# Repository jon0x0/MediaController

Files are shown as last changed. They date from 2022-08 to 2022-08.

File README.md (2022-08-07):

# MediaController

Design and programming by Jon Becker

This is a media controller to support sound art installations.

Goals are:
###  An external 'outside' button to open the door.
###  An internal 'user' button to indicate the user is in place and ready to begin, and to abort the experience if the user is uncomfortable continuing.
###  An operator button to assist with aborting the media.
###  LEDs on the buttons to indicate functions and status.
###  Bright internal RGBW LEDs (here implemented by Adafruit 4W Dotstars) which can be changed to a different color and brightness and controlled as desired.
###  A linear actuator to open and close the door.
###  A relay to control the media (on to reset and play, off to stop playing).

The system is implemented with an Adafruit Feather M4 Express microcontroller, and programmed in C using the Arduino IDE.
It was developed on Arduino IDE 1.8.19.
The software uses a realtime state machine architecture (where each state finishes very quickly), with a low-level (fast) state machine which controls button LED glow and flash behavior (and only a single 12ms delay for LED persistence), and a high level state machine for button transitions, device actuation etc.

# Libraries:
To install, the following libraries are needed (they can be installed through the Arduino Library Manager).
## 'Sparkfun QWIIC Relay' library
## 'Adafruit BUSIO' library
## 'Adafruit seesaw' library (for the button controller)

# Hardware used:

## [Adafruit Feather M4 Express](https://www.adafruit.com/product/3857)

## [Featherwing Breakout](https://www.adafruit.com/product/2926)

## [Short headers](https://www.adafruit.com/product/3002) and [stacking headers](https://www.adafruit.com/product/2830)

## [Adafruit 4W RGBW pixels](https://www.adafruit.com/product/5408)

Note that Adafruit recommends a 1000 uF capacitor (watch polarity) across the +5V and GND pins of the dotstars, and a 300-500 ohm resistor in series with the data line. Without this it *will* misbehave.

## Level shifter
This [level shifter](https://learn.sparkfun.com/tutorials/txb0104-level-shifter-hookup-guide) is used to shift interface levels from 3.3V of the M4 Express board to the 5V level required by the Dotstar LEDs.

## Sparkfun QWIIC / I2C relay module
[COM-15093 relay module](https://www.sparkfun.com/products/15093)

Works with Sparkfun QWIIC Relay library  (arduino auto library manager)
https://learn.sparkfun.com/tutorials/qwiic-single-relay-hookup-guide

## Buttons:
[Mini Arcade Buttons with integrated LED](https://www.adafruit.com/product/3432)

the bottom of the button has arrows for + and - on the LED connections.

## [Spade to JST-XH connectors](https://www.adafruit.com/product/1152)

## [QWIIC/STEMMA Button interface](https://www.adafruit.com/product/5296)

This is a button interface as a well as an LED controller for buttons with integrated LEDs.
driver in library manager is 'adafruit seesaw'
example in 'LEDArcade_1x4'
dependence is 'Adafruit BUSIO'

## [QWIIC breakout board](https://www.sparkfun.com/products/16790)

## Linear Actuator
[Yuelianart 8" Stroke Tracker Actuator Multi Function Linear Electric Actuator 12v Linear Actuator Stroke Speed 10mm/s 900N Load Capacity](https://www.amazon.com/gp/product/B09PYLGBRK/)
The spec says 2A no load, up to 7A with load. 12V@5A should be sufficient for most uses, but 7A might be needed for the highest loads. 

Note that this actuator has built in limit switches that will stop it at each end of the actuation.

## Motor driver:
[HiLetgo BTS7960](https://www.amazon.com/HiLetgo-BTS7960-Driver-Arduino-Current/dp/B00WSN98DC/)

Some diagrams and code 
https://www.youtube.com/watch?v=QvXa6GKLu6E

motor controller example
https://create.arduino.cc/projecthub/Fouad_Roboticist/dc-motors-control-using-arduino-pwm-with-l298n-h-bridge-d6ec91

Another example and library
https://robojax.com/learn/arduino/?vid=robojax_BTS7960_motor_driver#google_vignette

## Misc JST-SM wire to wire [connectors](https://www.adafruit.com/product/1663) (2,3,4,6 pins)

# Wiring pinout
See [here](https://docs.google.com/spreadsheets/d/1ZAK95VV2u1BcN2Gdv8SZK7Fb-S8OxHLf3jOhQMFysT0/edit?usp=sharing)

# Cables needed:
 These cables may be overkill, but the choice was influenced by how long they needed to be (which makes low resistance desirable), current capacity required (in some cases) and what cable was readily available.
 Cable was purchased from [this](https://www.amazon.com/gp/product/B07Y34F1ZV/) cable family.
 
 | Cable  | Length  | Spec  |
|---|---|---|
| outside+operator button  |  6m | 6c 20ga  |
| motor  | 6m  | 6c 18ga, tripled  |
| inside button  | 3m  | 4c 18ga  |
| lights  | 6m  | 3c 18ga  |
| audio footswitch | 3m | 3c 18ga |

# Operational notes:

When I tried to make an extension cable for the 4W Dotstar chain I couldn't get it working. I tried to build a shorter one which also didn't work. Then I remembered that the Dotstars kind of boost the signal at each stage, so I tried inserting the extension after the first Dotstar, and that worked (with either the 6m or 3m version).  I included both extensions I made. At the moment there are 5 total Dotstars to work with so you could even completely cover up the first one if you want and you still have a decent number to work with.

Probably I could have tried to change the resistor which is in line with the Dotstar data line to increase the drive strength- currently 330 ohm per Adafruit's recommendation of 300-500 ohms (reducing this might have helped). Anyway it takes time to figure those kinds of things out.

The main thing you're going to have to be careful with is to not reverse the 5V and 12V power, that would be disastrous. They are pretty well marked but it would definitely be possible to switch them.

The other thing is that you will still need a MicroUSB cable and a USB wall supply to power the processor (Adafruit Feather M4 Express).
And you will need a 1/4" plug cable to wire into the relay connection to start/stop the audio player.

I would recommend this powerup order: 5V, then USB power to the processor, then 12V. And the reverse to power down (or all at once with a power strip).

The enclosure was designed (with Fusion 360) so you can mount it to a surface and then screw the cover on top of it (it uses [M3 heat-set threaded inserts](https://www.mcmaster.com/94180A331/)). Also you can route cables either out of a slot on one edge of the cover or you can route cables through a slot in the base (it may not be possible but it's there if useful).

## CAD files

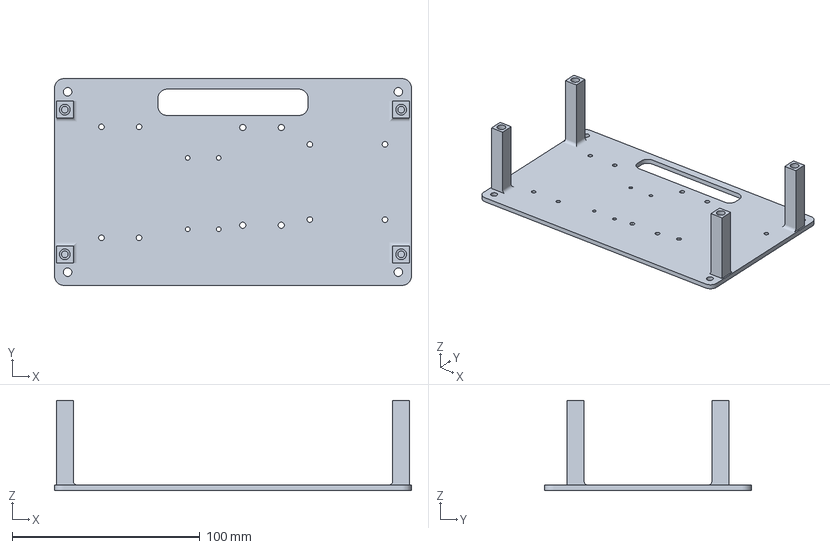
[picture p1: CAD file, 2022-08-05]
MediaControllerMountingTray v2.3mf
190.0 x 110.0 x 48.0 mm

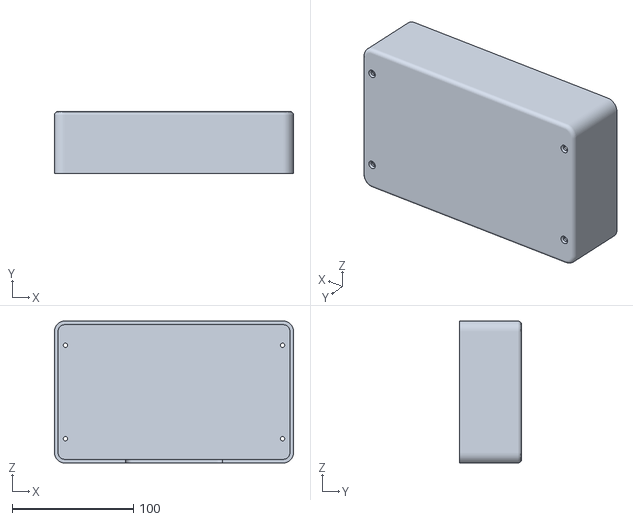
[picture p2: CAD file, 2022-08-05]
MediaControllerCover v3.stl
197.0 x 51.2 x 117.0

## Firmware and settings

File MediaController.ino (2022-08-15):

// Media Controller software
// Jon Becker 2022
// For Thembi Soddell's audio installation

// Master definitions

// Time from when user pushes button to when media starts (includes closing door).
#define BEGIN_CLOSING_DOOR_TO_MEDIA_START_SEC 20.0

// Total duration of media play before lights come on in floating point seconds. This should match the media play possibly plus a few seconds.
#define MEDIA_DURATION_SEC (12.0*60)

// Brightness of neopixel LEDs, 0-255 (255 is brightest).
#define NEOPIXEL_MASTER_BRIGHTNESS 255

// Number of Neopixels in the system.
#define NEOPIXEL1_COUNT 5

// Neopixel color. Each channel is 0 to 255.
#define NEOPIXEL_RED 255
#define NEOPIXEL_GREEN 0
#define NEOPIXEL_BLUE 0
#define NEOPIXEL_WHITE 50

// Speed of door motor (0-255). Probably want to leave this at 255. Even at full speed it's pretty slow. If it is too slow the actuator will not move.
#define MOTOR_SPEED 255

// Include Arduino Wire library for I2C

// Definitions for Arcade button+LED controller 1x4, from LEDArcade_1x4
#include "Adafruit_seesaw.h"
#include <seesaw_neopixel.h>

#define  DEFAULT_I2C_ADDR 0x3A

#define  SWITCH1  18  // PA01
#define  SWITCH2  19 // PA02
#define  SWITCH3  20 // PA03
#define  SWITCH4  2 // PA06
#define  PWM1  12  // PC00
#define  PWM2  13 // PC01
#define  PWM3  0 // PA04
#define  PWM4  1 // PA05


Adafruit_seesaw ss;

enum buttonledstates
{
  B_LEDON_STATE = 0,
  B_LEDON_STATE2,
  B_LEDOFF_STATE,
  B_LEDOFF_STATE2,
  B_LEDONLOW_STATE,
  B_LEDONLOW_STATE2,
  B_LEDGLOW_STATE,
  B_LEDGLOWPULSE_STATE,
  B_LEDGLOWPULSE_STATE2,
  B_LEDFLASH_STATE,
  B_LEDFLASH_STATE2,
  B_LEDFLASH_STATE3,
  B_LEDFADEIN_STATE,
  B_LEDFADEIN_STATE2
};

// Define the number of buttons in the system.
#define NBUTTONS 3

// Pushbutton LED glow pulse width modulation
uint8_t masterbuttonledpwm = 0;  // You could use this to synchronize multiple button glows.
// Button led pwm fro multiple buttons;
uint8_t buttonledpwm[NBUTTONS + 1];


// Definitions for the relay (used to control audio player)
#include <Wire.h>
#include "SparkFun_Qwiic_Relay.h"
#define RELAY_ADDR 0x18 // Alternate address 0x19
Qwiic_Relay relay(RELAY_ADDR);

// Definitions for the 4W GRBW Neopixels
#include <Adafruit_NeoPixel.h>
// Which pin on the Arduino is connected to the NeoPixels?
#define NEOPIXEL1_PIN    14

// Declare our NeoPixel strip object:
Adafruit_NeoPixel strip1(NEOPIXEL1_COUNT+1, NEOPIXEL1_PIN, NEO_RGBW + NEO_KHZ800);
// Argument 1 = Number of pixels in NeoPixel strip
// Argument 2 = Arduino pin number (most are valid)
// Argument 3 = Pixel type flags, add together as needed:
//   NEO_KHZ800  800 KHz bitstream (most NeoPixel products w/WS2812 LEDs)
//   NEO_KHZ400  400 KHz (classic 'v1' (not v2) FLORA pixels, WS2811 drivers)
//   NEO_GRB     Pixels are wired for GRB bitstream (most NeoPixel products)
//   NEO_RGB     Pixels are wired for RGB bitstream (v1 FLORA pixels, not v2)
//   NEO_RGBW    Pixels are wired for RGBW bitstream (NeoPixel RGBW products)


// Definitions for motor controller
#define MotorPin_D1_L  9 //Rpwm
#define MotorPin_D2_L  10 //Lpwm
#define MotorPin_E_L   11 //pwm enable (connected to two pins on the motor driver)


void setup()
{
  motor_setup();

  // put your setup code here, to run once:
  Serial.begin(115200);

//  while (!Serial) delay(10);   // wait until serial port is opened

  Serial.println(F("Media Controller"));

  // Initialize arcade button interface
  if (!ss.begin(DEFAULT_I2C_ADDR))
  {
    Serial.println(F("seesaw button controller not found!"));
    while (1) delay(10);
  }

  uint16_t pid;
  uint8_t year, mon, day;

  ss.getProdDatecode(&pid, &year, &mon, &day);
  Serial.print("seesaw button controller found PID: ");
  Serial.print(pid);
  Serial.print(" datecode: ");
  Serial.print(2000 + year); Serial.print("/");
  Serial.print(mon); Serial.print("/");
  Serial.println(day);

  if (pid != 5296)
  {
    Serial.println(F("Wrong seesaw button controller PID"));
    while (1) delay(10);
  }

  Serial.println(F("seesaw started OK!"));
  ss.pinMode(SWITCH1, INPUT_PULLUP);
  ss.pinMode(SWITCH2, INPUT_PULLUP);
  ss.pinMode(SWITCH3, INPUT_PULLUP);
  ss.pinMode(SWITCH4, INPUT_PULLUP);
  ss.analogWrite(PWM1, 127);
  ss.analogWrite(PWM2, 127);
  ss.analogWrite(PWM3, 127);
  ss.analogWrite(PWM4, 127);

  buttonledpwm[0] = 0; // unused but leave nothing uninitialized.
  for (int i = 1; i < NBUTTONS + 1; ++i)
    buttonledpwm[i] = 0;

  SetButtonLEDState(0, B_LEDON_STATE2);
  SetButtonLEDState(1, B_LEDGLOWPULSE_STATE);
  SetButtonLEDState(2, B_LEDGLOWPULSE_STATE);

  // Init the audio player relay
  Wire.begin();

  // Let's see
  if (!relay.begin())
    Serial.println("Check connections to Qwiic Relay.");
  else
    Serial.println("Relay control initialized.");

  Init_Neopixels();

} //setup()



void loop()
{
  // put your main code here, to run repeatedly:

  ProcStateMachine();

} // loop()

int state = 0;

enum states
{
  START_STATE = 0,
  ATTRACT_STATE,
  OPEN_DOOR_STATE,
  OPEN_DOOR_STATE2,
  WAIT_FOR_MEDIA_BUTTON_STATE,
  CLOSE_DOOR_STATE,
  PLAYING_MEDIA_STATE,
  PLAYING_MEDIA_STATE2
};

unsigned long statetimer;
unsigned long mediatimer;
unsigned long operatordebouncetimer;
unsigned long debouncetimer;

void ProcStateMachine()
{
  switch (state)
  {
    case START_STATE: // starting state. Use for some setup / going back to the beginning.
      // Nothing here at the moment
      TurnOffAudioPlayer();
      TurnNeopixelsOn();
      //SetButtonLEDState(0,B_LEDFADEIN_STATE);
      SetButtonLEDState(1, B_LEDGLOWPULSE_STATE);
      SetButtonLEDState(2, B_LEDOFF_STATE);
      operatordebouncetimer = SetTimer_sec(5.0);

      state++;
      Serial.println(F("Start state complete. Moving to attract state."));
      break;

    case ATTRACT_STATE:  // The initial state to glow button and wait for a button push.

      if (! ss.digitalRead(SWITCH1))
      {
        Serial.println("Switch 1 pressed");
        TurnNeopixelsOn();
        SetButtonLEDState(1, B_LEDFLASH_STATE);
        SetButtonLEDState(2, B_LEDGLOWPULSE_STATE);
        state++;
      }
      if (! ss.digitalRead(SWITCH3) && IsTimerFinished(operatordebouncetimer))    // Operator switch
      {
        Serial.println("Switch 3 pressed");
        Serial.println("Closing door.");
        CloseDoor();
        TurnNeopixelsOff();
        operatordebouncetimer = SetTimer_sec(5.0);
        // remain in this state.
      }
      break;

    case OPEN_DOOR_STATE:
      // actuate the door open
      OpenDoor();
      state++;
      break;

    case OPEN_DOOR_STATE2:
      state++;
      break;

    // waiting for the user to push the button inside to begin the media
    case WAIT_FOR_MEDIA_BUTTON_STATE:
      if (! ss.digitalRead(SWITCH3) )    // Operator switch
      {
        state = START_STATE; // reset back to the beginning.
      }

      if (! ss.digitalRead(SWITCH2))
      {
        Serial.println("Switch 2 pressed");
        CloseDoor();
        TurnNeopixelsOff();
        SetButtonLEDState(1, B_LEDFLASH_STATE);
        SetButtonLEDState(2, B_LEDONLOW_STATE); // turn on led steady and dim so it isn't a distraction in the dark. May want to dim it further or turn it off altogether (but nice to have a way to find it in the dark).
        statetimer = SetTimer_sec(BEGIN_CLOSING_DOOR_TO_MEDIA_START_SEC);
        debouncetimer = SetTimer_sec(3.0);
        state++;
      }
      break;

    case CLOSE_DOOR_STATE:
      // wait for a time past button release before accepting an abort
      if (IsTimerFinished(debouncetimer))  // allow an abort with the operator switch during this period after a short debounce period.
      {
        if (! ss.digitalRead(SWITCH3))    // Operator switch
        {
          Serial.println("Switch 3 pressed");
          Serial.println("Opening door.");
          OpenDoor();
          state = START_STATE;  // this will turn off the audio player and turn on the neopixels.
        }
      }
      if (IsTimerFinished(statetimer) == true)
        state++;
      break;

    case PLAYING_MEDIA_STATE:
      TurnOnAudioPlayer();
      mediatimer = SetTimer_sec(MEDIA_DURATION_SEC);
      state++;
    break;

    case PLAYING_MEDIA_STATE2:
      if (! ss.digitalRead(SWITCH3))    // Operator switch
      {
        Serial.println("Switch 3 pressed");
        Serial.println("Opening door.");
        OpenDoor();
        state = START_STATE;  // this will turn off the audio player and turn on the neopixels.
      }

      if (IsTimerFinished(mediatimer) == true)
      {
        Serial.println("Media timer complete");
        OpenDoor();
        state = START_STATE;  // this will turn off the audio player and turn on the neopixels.

      }

      if (! ss.digitalRead(SWITCH2))   // If abort button is pressed
      {
        Serial.println("Switch 2 pressed- abort media");
        Serial.println("Open Door");
        OpenDoor();

        // Tell the neopixels to fade in.
        SetButtonLEDState(0, B_LEDFADEIN_STATE);

        //        TurnOffAudioPlayer();
        //        SetNeopixelsOn();
        state = START_STATE;  // this will turn off the audio player and turn on the neopixels.
      }
      break;


    default:
      state = 0;
      break;

  } //switch

  ProcButtonLEDs();  // These are always processed. May as well do it here.

} //ProcStateMachine


int b1_led_state = 0;

int button_led_state[NBUTTONS + 1];

void SetButtonLEDState(int button, int state)
// Call to change the button LED to a particular mode (off/glow/flash etc).
{
  button_led_state[button] = state;
}

void SetButtonLED_PWM(int button, uint8_t pwm)
// Change the LED brightness for a particular button. Normally called by the button led state machine.
{
  switch (button)
  {
    case 0:  // This is actually the neopixel chain.
      //strip1.setBrightness(NEOPIXEL_MASTER_BRIGHTNESS*pwm/255);
      //SetNeopixelsFade(pwm);
      break;

    case 1:
      ss.analogWrite(PWM1, pwm);  // turn off button led
      break;

    case 2:
      ss.analogWrite(PWM2, pwm);  // turn off button led
      break;

    default:
      break;

  } // switch button

} // SetButtonLED_PWM

int flashcount = 0;
// Define number of cycles to flash, each cycle lasts for whatever the delay is (probably 12 msec). So NCYCLES_TO_FLASH = 10 would be 120 msec for each on/off time in this example.
#define NCYCLES_TO_FLASH 10

void ProcButtonLED(int button)
// Process the LED behavior for a particular button.
{
  int state, ledpwm;
  state = button_led_state[button];
  ledpwm = buttonledpwm[button];

  if (1) // disabled check
  {
    switch (state)
    {

      case B_LEDON_STATE:
        SetButtonLED_PWM(button, 255); // turn on button led
        state++;
        break;

      case B_LEDON_STATE2:
        // led is on now, do nothing
        break;


      case B_LEDOFF_STATE:
        SetButtonLED_PWM(button, 0); // turn off button led
        state++;
        break;

      case B_LEDOFF_STATE2:
        // led is off now, do nothing
        break;

      case B_LEDONLOW_STATE:
        SetButtonLED_PWM(button, 5); // turn on button led, low brightness
        state++;
        break;

      case B_LEDONLOW_STATE2:
        // led is on now, do nothing
        break;

      case B_LEDGLOW_STATE:
        SetButtonLED_PWM(button, ledpwm);
        ledpwm += 5; // glow LED by increasing PWM (it wraps around to zero and keeps increasing)
        break;

      case B_LEDGLOWPULSE_STATE:
        SetButtonLED_PWM(button, ledpwm);
        ledpwm += 5;  // increasing
        if (ledpwm == 255)
          state++;
        break;

      case B_LEDGLOWPULSE_STATE2:
        SetButtonLED_PWM(button, ledpwm);
        ledpwm -= 5;  // decreasing
        if (ledpwm == 0)
          state = B_LEDGLOWPULSE_STATE;  // repeat glowpulse cycle
        break;

      case B_LEDFLASH_STATE:
        SetButtonLED_PWM(button, 255); // turn on button LED
        state++;
        break;

      case B_LEDFLASH_STATE2:
        flashcount++;
        if (flashcount > NCYCLES_TO_FLASH)
        {
          flashcount = 0;
          SetButtonLED_PWM(button, 0); // turn off button LED
          state++;
        }

      case B_LEDFLASH_STATE3:
        flashcount++;
        if (flashcount > NCYCLES_TO_FLASH)
        {
          flashcount = 0;
          state = B_LEDFLASH_STATE;  // repeat the flash cycle
        }
        break;

      case B_LEDFADEIN_STATE:
        ledpwm = 0;
        SetButtonLED_PWM(button, ledpwm);
        ledpwm += 1;  // increasing
        if (ledpwm == 255)
          state++;
        break;

      case B_LEDFADEIN_STATE2:
        // led is on now, do nothing
        break;

      default:
        break;

    } // switch b_led_state
  } // if
  button_led_state[button] = state;  // save any state change for this button
  buttonledpwm[button] = ledpwm;     // save modified led pwm value
} //ProcButtonLED


void LED_Delay()
// This is the system delay after processing the smallest state. Should be quick enough for persistence of vision on the LEDs.
// Call once per state, after updating button PWMs.
{
  delay(12);  // in milliseconds.
}


void ProcButtonLEDs()
// Process all button LEDs and add the delay.
{
  //  ProcButtonLED(0);  // neopixel brightness
  ProcButtonLED(1);
  ProcButtonLED(2);
  LED_Delay();  // call after updating all button LEDs
}

void TurnOnAudioPlayer()
{
  Serial.println("Starting audio player");
  relay.turnRelayOn();
}

void TurnOffAudioPlayer()
{
  Serial.println("Turning off audio player");
  relay.turnRelayOff();
}

void Init_Neopixels()
{
  strip1.begin();           // INITIALIZE NeoPixel strip object (REQUIRED)
  strip1.show();            // Turn OFF all pixels ASAP
  strip1.setBrightness(NEOPIXEL_MASTER_BRIGHTNESS); // Set BRIGHTNESS to about 1/5 (max = 255)
}

void TurnNeopixelsOff()
{
  for (int i = 0; i < NEOPIXEL1_COUNT; ++i)
    strip1.setPixelColor(i, strip1.Color(0, 0, 0) );       //  Set pixel's color (in RAM)
  strip1.show();
}

void TurnNeopixelsOn()
{
  for (int i = 0; i < NEOPIXEL1_COUNT; ++i)
    strip1.setPixelColor(i, strip1.Color(NEOPIXEL_RED, NEOPIXEL_GREEN, NEOPIXEL_BLUE, NEOPIXEL_WHITE) );       //  Set pixel's color (in RAM)
  strip1.show();
}

void SetNeopixelsFade(int fade)
// Fade neopixel using the color setting and math.
{
  for (int i = 0; i < NEOPIXEL1_COUNT+1; ++i)
    strip1.setPixelColor(i, strip1.Color(NEOPIXEL_RED * fade / 255, NEOPIXEL_GREEN * fade / 255, NEOPIXEL_BLUE * fade / 255) ); //  Set pixel's color (in RAM)
  strip1.show();
}

unsigned long SetTimer_sec(float duration_sec)
{
  unsigned long endtime = millis() + floor(duration_sec * 1000);
  return endtime;
}

bool IsTimerFinished(unsigned long endtime)
{
  if (millis() > endtime)
    return true;
  else
    return false;
}

void CloseDoor()
{
  motor_cw();
  Serial.println("Close Door");
}

void OpenDoor()
{
  motor_ccw();
  Serial.println("Open Door");
}


void motor_setup()
{
  pinMode(MotorPin_D1_L, OUTPUT);
  pinMode(MotorPin_D2_L, OUTPUT);
  pinMode(MotorPin_E_L, OUTPUT);
  motor_stop();
}

void motor_test()
{
  motor_stop();   delay(1000);
  motor_cw();     delay(1000);
  motor_stop();   delay(1000);
  motor_ccw();     delay(1000);
}

void motor_cw()
{
  analogWrite(MotorPin_E_L, MOTOR_SPEED); //0-255
  digitalWrite(MotorPin_D1_L, HIGH);
  digitalWrite(MotorPin_D2_L, LOW);
}

void motor_ccw()
{
  analogWrite(MotorPin_E_L, MOTOR_SPEED); //0-255
  digitalWrite(MotorPin_D1_L, LOW);
  digitalWrite(MotorPin_D2_L, HIGH);
}

void motor_stop()
{
  digitalWrite(MotorPin_D1_L, LOW);
  digitalWrite(MotorPin_D2_L, LOW);
  analogWrite(MotorPin_E_L, 0);
}

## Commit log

2022-08-05 3D Printed mounting tray and enclosure cover
    [MediaControllerCover v3.stl, MediaControllerMountingTray v2.3mf]
2022-08-15 Update MediaController.ino
    Repaired the file- somehow a few lines had been accidentally deleted. Used history to repair it, hopefully nothing missed.
    [MediaController.ino]
